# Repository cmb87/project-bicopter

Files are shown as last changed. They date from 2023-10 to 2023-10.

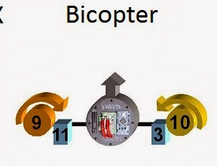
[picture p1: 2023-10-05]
imgs/bicopter.png

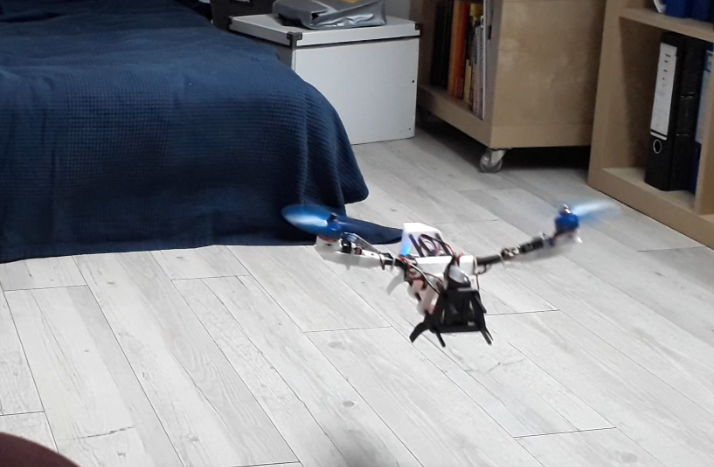
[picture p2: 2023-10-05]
imgs/inflight2.png

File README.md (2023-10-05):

# Bicopter (WIP!)

bicopter with ardiuno, esp, multiwii etc...

# Construction

See https://www.thingiverse.com/thing:6250313

Tilt mechanism is a remix from: https://www.thingiverse.com/thing:1026731

## To buy

    4x 5x5mm carbon rectangular profile
    2x 8x8mm carbon rectangular profile
    2x Emax rs2205
    2x 30A ESC OPTO
    2x MicroServo
    1x Arduino Nano
    1x Battery 75C 11.1V 850mAh
    1x Matek

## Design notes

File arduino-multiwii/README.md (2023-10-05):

# Generic Arduino Based Flightcontroller

## Code
There are two versions:

## MultiWii based FC code
(see https://github.com/multiwii/multiwii-firmware.git for more details). 

### Compass module
Some modifications of the original code were necessary for the compass module (QMC5883L) and are described here:
https://forum.arduino.cc/index.php?topic=556590.0

0.) Navigate to config.h add the line somewhere behind /* I2C magnetometer */:

        #define QMC5883
        
1.) Navigate to sensors.cpp add following somewhere behind the last #endif statement at the magnetometer section:

        // ************************************************************************************************************
        // I2C Compass QMC5883L
        // ************************************************************************************************************
        // I2C adress: 0x0D (7bit)
        // ************************************************************************************************************
        #if defined(QMC5883)

        #define MAG_ADDRESS 0x0D
        #define MAG_DATA_REGISTER 0x00

        //REG CONTROL

        #define MAG_CTRL_REG1 0x09
        #define QMC_MODE 0xC1 // 11 00 00 01OSR=64(11); Range=2G(00); ODR=10Hz(00); MODE=Cont(01)
        #define MAG_CTRL_REG2 0x0A

        void Mag_init() {
          i2c_writeReg(MAG_ADDRESS,0x0B,0x01);
          i2c_writeReg(MAG_ADDRESS,MAG_CTRL_REG1,QMC_MODE);
        }

        static void getADC() {
          i2c_getSixRawADC(MAG_ADDRESS,MAG_DATA_REGISTER);
          MAG_ORIENTATION( ((rawADC[1]<<8) | rawADC[0]) ,
                           ((rawADC[3]<<8) | rawADC[2]) ,
                           ((rawADC[5]<<8) | rawADC[4]) );
        }

        #if !defined(MPU6050_I2C_AUX_MASTER)
        static void Device_Mag_getADC() {
          getADC();
        }
        #endif
        #endif

Now we need to add the QMC to the MPU6050 I2C Master & Slave functionality:

Search for this comment in sensors.cpp:

        //The MAG acquisition function must be replaced because we now talk to the MPU device

Add following lines inside static void Device_Mag_getADC(){} after i2c_getSixRawADC(MPU6050_ADDRESS, 0x49);:

        #if defined(QMC5883)
                MAG_ORIENTATION( ((rawADC[1]<<8) | rawADC[0]) ,
                                 ((rawADC[3]<<8) | rawADC[2]) ,
                                 ((rawADC[5]<<8) | rawADC[4]) );
              #endif
              
Navigate to def.h search for the MAG 1 definition "#if" clause - add "|| defined(QMC5883)" - like this:

        #if defined(HMC5883) || defined(HMC5843) || defined(AK8975) || defined(MAG3110) || defined(QMC5883)
          #define MAG 1
        #else
          #define MAG 0
        #endif
              
The original HMC5883 Code has lots of more lines because of some ominous bias and gain settings - the QMC5883 lacks those registers - Unfortunately I don't have any knowledge about this and its benefits and no time to get into it. The data provided by the sensor seems to be reliable.

### Setup
Due to the construction of the flight controller the following settings were necessary:
            
          MINTHROTTLE = 1150
          # ==============================================
          # MPU Setup 
          # ==============================================
          # Roll and Yaw inverted
          #define ACC_ORIENTATION(X, Y, Z) {imu.accADC[ROLL] =  -X; imu.accADC[PITCH] =  -Y; imu.accADC[YAW] = Z;}
          #define GYRO_ORIENTATION(X, Y, Z) {imu.gyroADC[ROLL] = -X; imu.gyroADC[PITCH] = -Y; imu.gyroADC[YAW] = Z;}
          
          # ==============================================
          # Inverted Pitch ... let's see ===> Not a good idea ... Create oscillations!
          #define ACC_ORIENTATION(X, Y, Z) {imu.accADC[ROLL] =  X; imu.accADC[PITCH] =  Y; imu.accADC[YAW] = -Z;}
          #define GYRO_ORIENTATION(X, Y, Z) {imu.gyroADC[ROLL] = -X; imu.gyroADC[PITCH] = Y; imu.gyroADC[YAW] = -Z;}

          # ==============================================
          WORKING!!!!
          # Roll and Yaw inverted ==> Stabilize around roll axis! Roll appears inverted in MultiwiiConf!!!
          #define ACC_ORIENTATION(X, Y, Z) {imu.accADC[ROLL] =  X; imu.accADC[PITCH] =  -Y; imu.accADC[YAW] = -Z;}
          #define GYRO_ORIENTATION(X, Y, Z) {imu.gyroADC[ROLL] = -X; imu.gyroADC[PITCH] = -Y; imu.gyroADC[YAW] = -Z;}
          # PID Coeff; Roll; 4.1, 0.004,9 Pitch:1.6, 0.003,4 Yaw: 1.6, 0.003, 2
          
          # ==============================================
          # MPU + Compass
          # ==============================================
          WORKING!!!! Works perfectly with 
          #define YAW_DIRECTION -1
          #define ACC_ORIENTATION(X, Y, Z) {imu.accADC[ROLL] =  X; imu.accADC[PITCH] =  -Y; imu.accADC[YAW] = -Z;}
          #define GYRO_ORIENTATION(X, Y, Z) {imu.gyroADC[ROLL] = -X; imu.gyroADC[PITCH] = -Y; imu.gyroADC[YAW] = -Z;}
          #define FORCE_MAG_ORIENTATION(X, Y, Z)  {imu.magADC[ROLL]  =   -X; imu.magADC[PITCH]  =  -Y; imu.magADC[YAW]  = -Z;}

### ESC Calibration
Dont forget the ESC calibration in config.h!

### Custom Arduino based FC code
Inspired by http://www.electronoobs.com

## PCB
Created with Fritzing and Flatcam.

# Issues
Some issues encountered during the construction phase.

## Vibrations
Has a very intensive impact on PID controller resulting in twitches and an in general "nervous" behaviour of the quad. In order to mitigate there are three ways:

    1.) Reduce vibrations by accurately balancing propellers
    2.) Increase damping of the flight controller module
    3.) In MultiWii: Reduce low pass filter to e.g. 42hz for gyro and activate moving average filter (with default settings). Search for LPF in config.h

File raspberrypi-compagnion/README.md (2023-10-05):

# Robotic SocketIO Control Stack
Computer Vision enhanced custom analytics

# Setup

## WiP

    scp -rv * pi@raspberrypi:/home/pi/projects/06_servoTest/.

## Start pigpio on start up

    sudo systemctl enable pigpiod

will enable it to auto-start on boot.

will start it immediately (just a posh way of doing

    sudo pigpiod

:)

If you change your mind,

    sudo systemctl disable pigpiod

will undo the start-up behaviour. Similarly,

    sudo systemctl stop pigpiod

will have an immediate effect.

## PWM Connection PiZero <-> FC

    Throttle D2 - GPIO 5
    Roll     D4 - GPIO 6
    Pitch    D5 - GPIO 13
    Yaw      D6 - GPIO 19
    Aux1     D7 - GPIO 26
    Aux1     D7 - GPIO 16
    Aux1     D7 - GPIO 20
    Aux1     D7 - GPIO 21
    G        GND
    
## Run Python script on every startup
Head over to /etc/profile, add command to start the Python script

    ...
    python3 /home/pi/..../app.py

## Issues

### RPI Slow Wifi network connection

Source (https://raspberrypi.stackexchange.com/questions/52066/pi3-wifi-extremely-slow)
Make sure power management is off on Pi.

    iwconfig

You should see something like this

    Power Management:off

If not, you can switch it to off by using

    sudo iwconfig wlan0 power off

If you want to make this permanent you should add the following line to /etc/rc.local (explanation here):

    iwconfig wlan0 power off

## Based on WiiProxy

https://github.com/engineer-99b/WiiProxy

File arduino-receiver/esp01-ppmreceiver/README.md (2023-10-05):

# Websocket based drone system

## Demo with FD411 Flightcontroller and ESP8266

## SocketIO Versions

	Python:
		Flask==1.1.2
		Flask-Cors==3.0.9
		gevent==20.6.2
		gevent-websocket==0.10.1
		python-engineio==3.13.2
		python-socketio==4.6.1
		Flask-SocketIO==4.3.1
    
	Arduino:
		SocketIOClient==0.3.0 (Vincent Wyszynski)
		WebSockets==2.3.1 (Markus Sattler)

	Angular:
		npm i --save socket.io-client@2.3.1
	Node:
		socket.io": {"version": "2.3.0"}
		engine.io  "version": "3.4.2",
		engine.io-client  3.4.4

## Connection Flightcontroller - Receiver

### PPM FD411 Flightcontroller Betaflight
		FD411s => ESP01
		3.3V => Pin 8 
		GND => Pin1
		RX2 => Pin2 (GPIO1)

## Connections for SBUS
https://github.com/bolderflight/SBUS

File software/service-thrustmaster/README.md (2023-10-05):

# Joystick

Microservice which reads the input of a connected Thrustmaster.
Commands are transferred via socketIO to a MultiWii or Betaflight compatible Device.

### Add Thrustmaster USB Joystick
Device wasnt showed as /dev/ttyUSB0. According to website (https://www.linuxquestions.org/questions/linux-server-73/ttyusb0-not-showing-up-in-dev-827416/):

        mknod /dev/ttyUSB0 c 188 0

# Docker

        docker build -t cmb87/skylink-thrustmaster:latest -f docker/Dockerfile .
        docker run --privileged -v /dev:/dev -e ENV_SOCKETIOSERVER="192.168.2.138"  joystick:latest
        docker push  cmb87/skylink-thrustmaster:latest

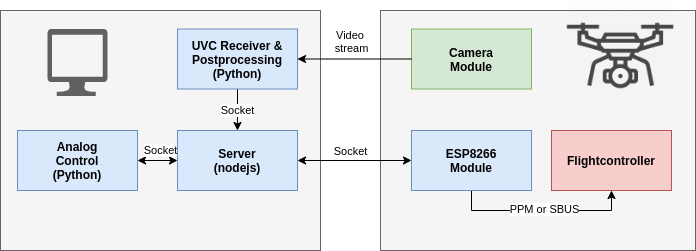
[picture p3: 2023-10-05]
imgs/architecture.png

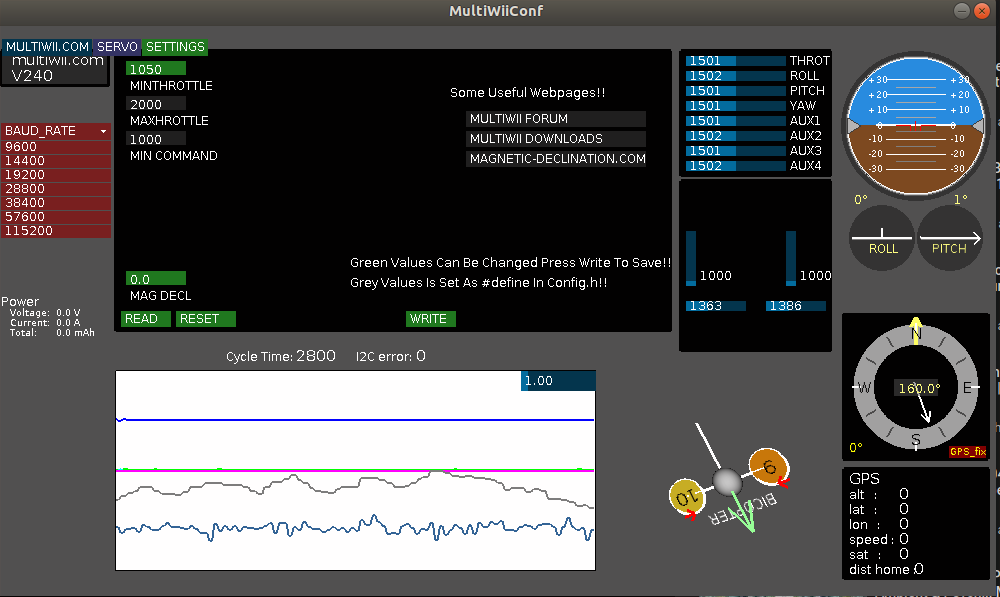
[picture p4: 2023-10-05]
imgs/mw3.png

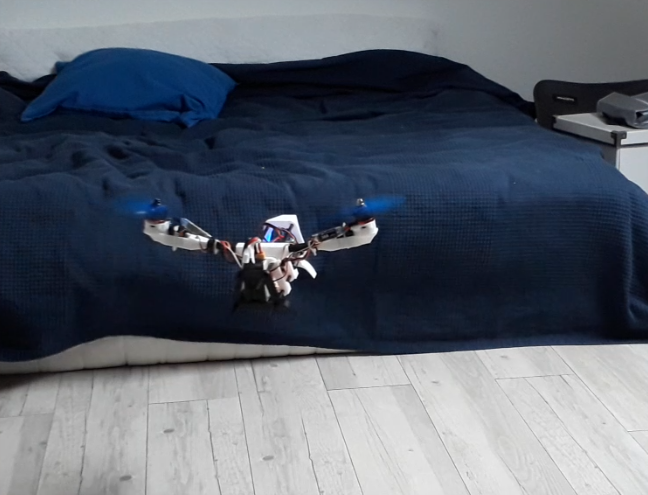
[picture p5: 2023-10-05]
imgs/inflight3.png

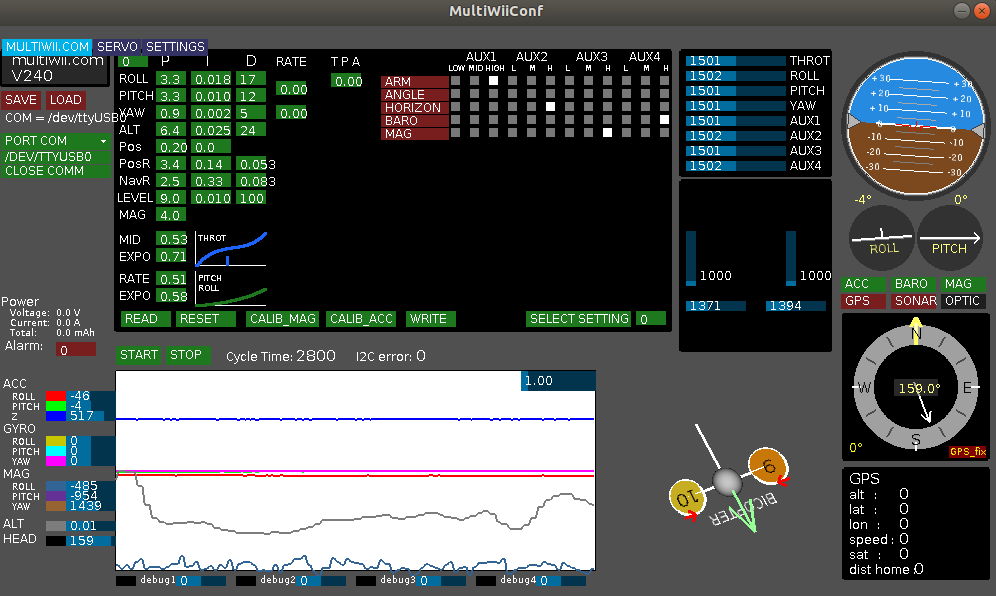
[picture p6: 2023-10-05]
imgs/mw1.png

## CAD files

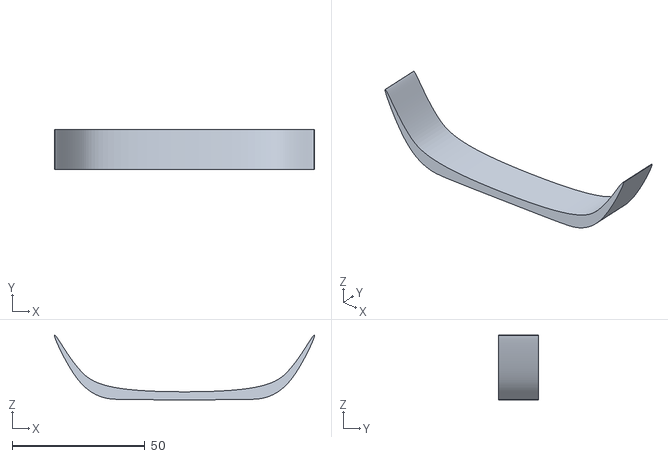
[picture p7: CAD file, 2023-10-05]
construction/3dprinted/landingGearRaw.stl
97.8 x 15.0 x 24.3

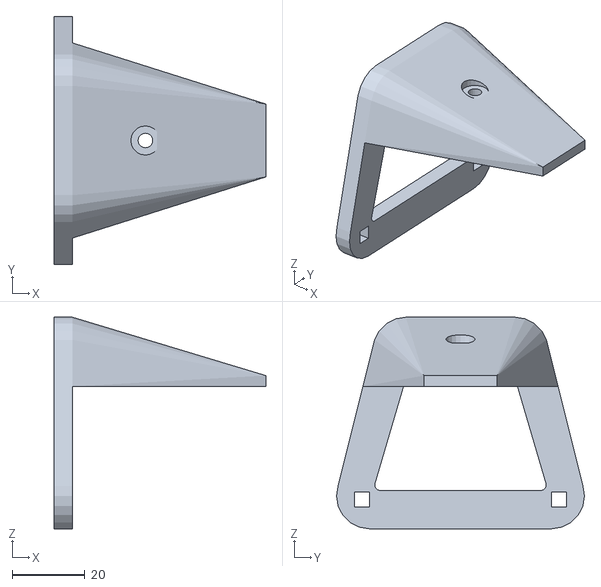
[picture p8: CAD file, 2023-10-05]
construction/3dprinted/nose.stl
58.0 x 68.0 x 58.0

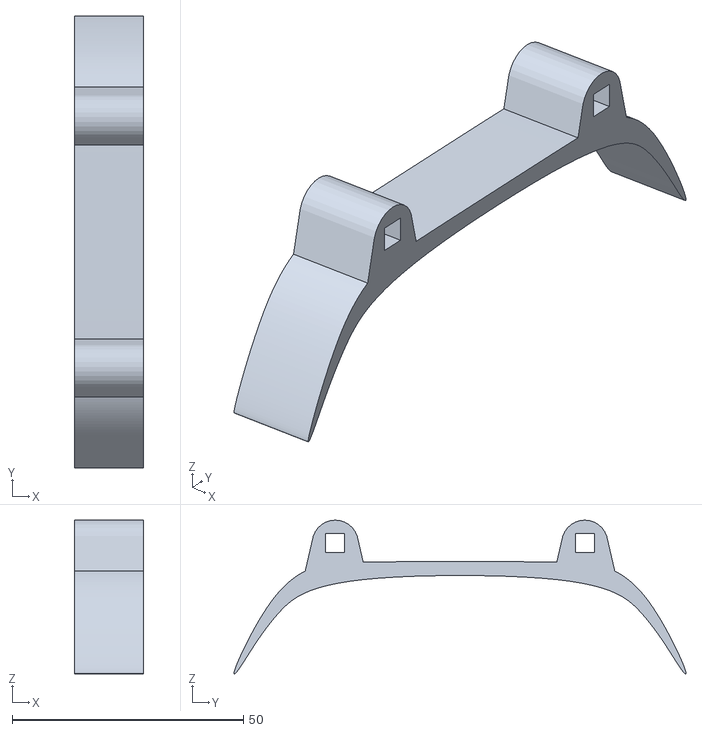
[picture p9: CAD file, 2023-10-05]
construction/3dprinted/landinggearWithoutHolders.stl
15.0 x 97.8 x 33.3

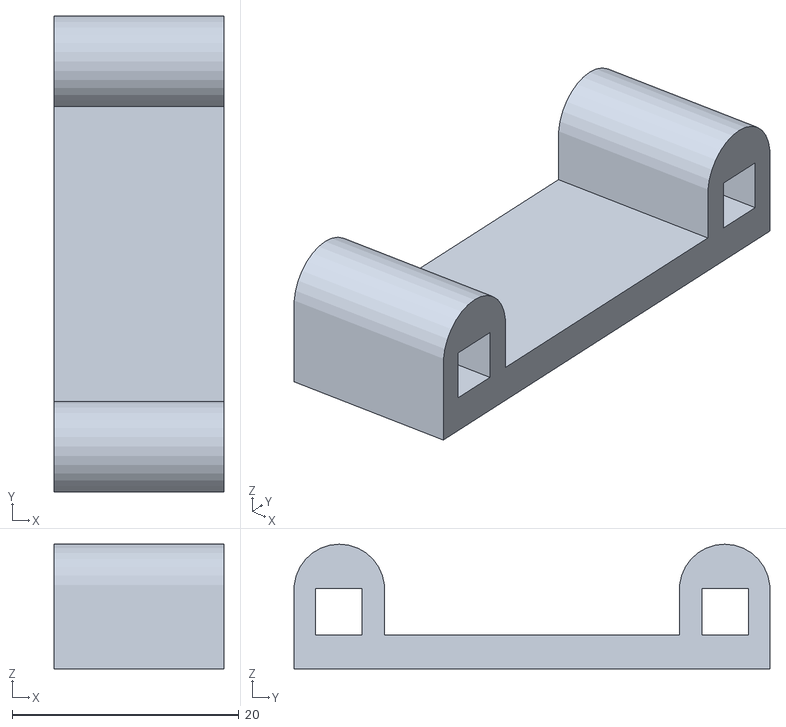
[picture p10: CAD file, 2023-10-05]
construction/3dprinted/gpsholder.stl
15.0 x 42.0 x 11.0

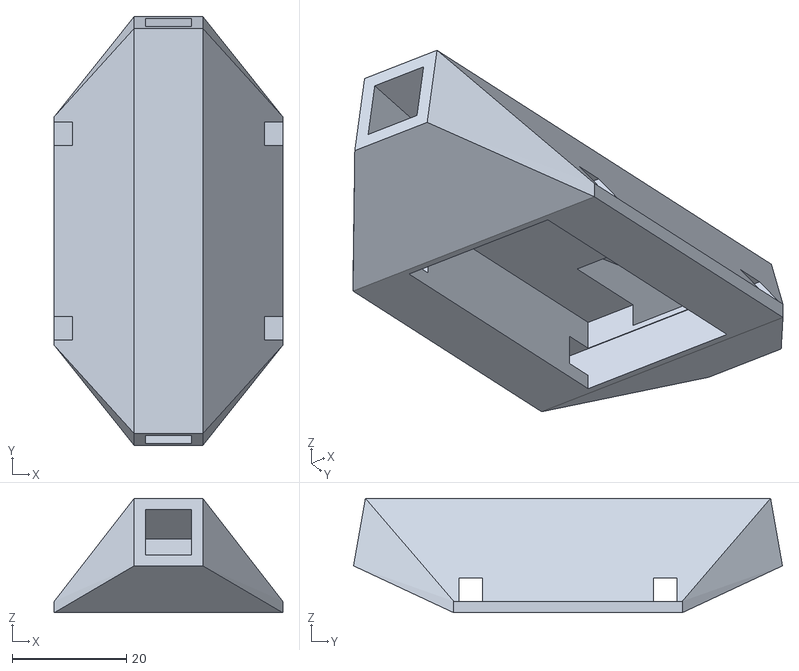
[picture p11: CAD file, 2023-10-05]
construction/3dprinted/frame.stl
40.0 x 75.1 x 20.0

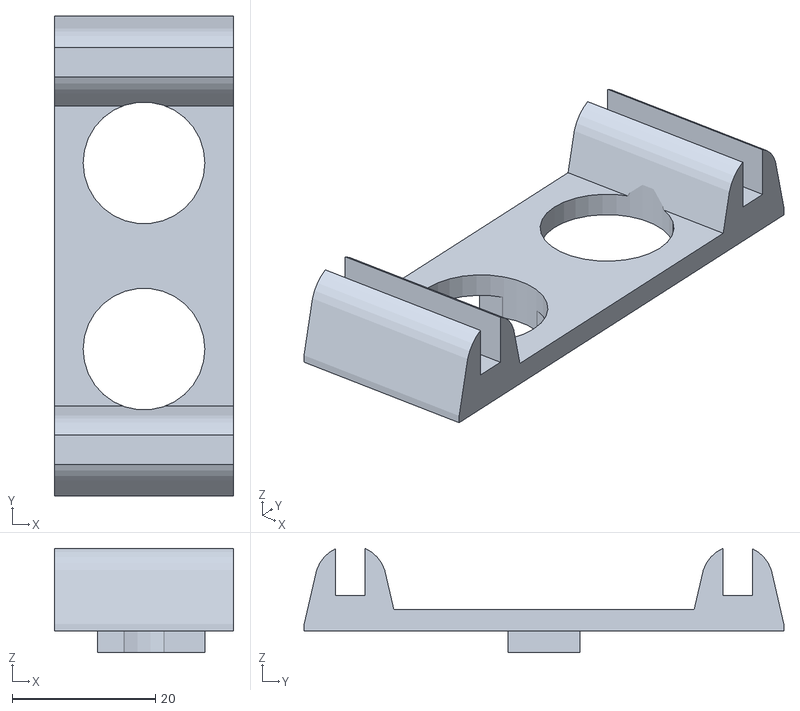
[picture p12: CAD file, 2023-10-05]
construction/3dprinted/sonarholder.stl
25.0 x 67.0 x 14.6

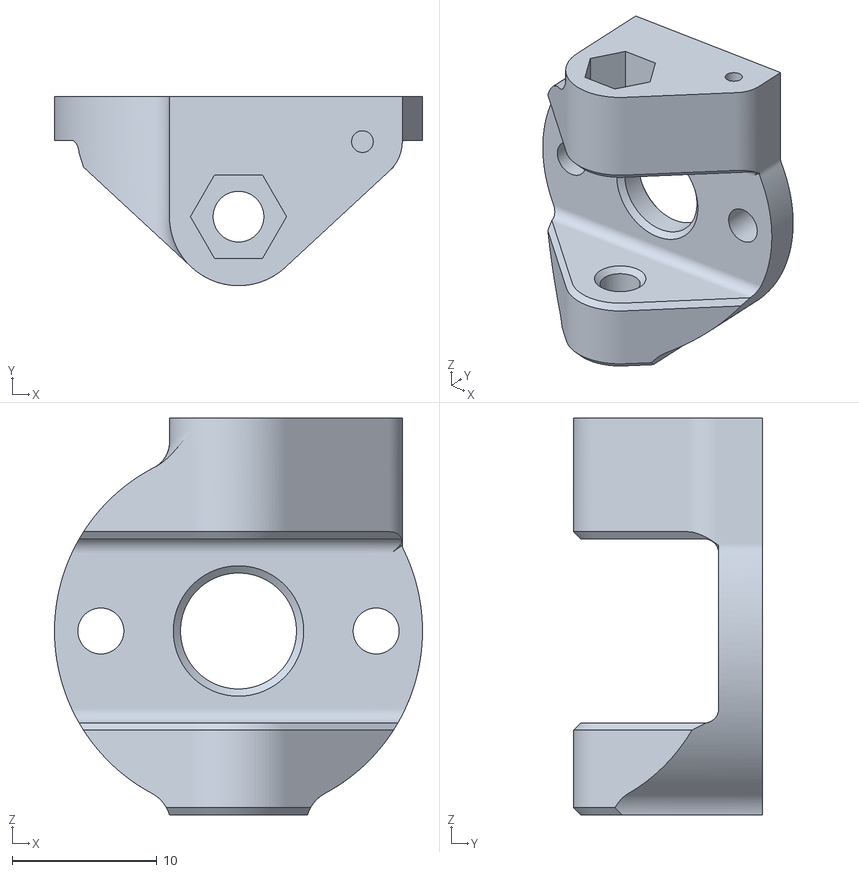
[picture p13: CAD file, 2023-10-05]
construction/3dprinted/TAIL_TILT_V2.stl
25.4 x 13.1 x 27.4

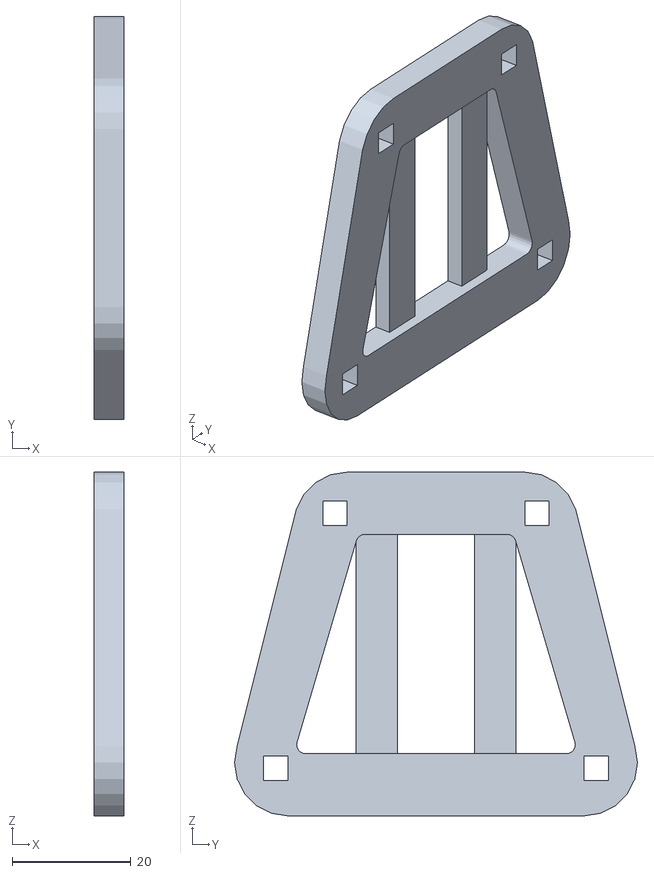
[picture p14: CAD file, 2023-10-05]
construction/3dprinted/batteryBody.stl
5.00 x 68.0 x 58.0

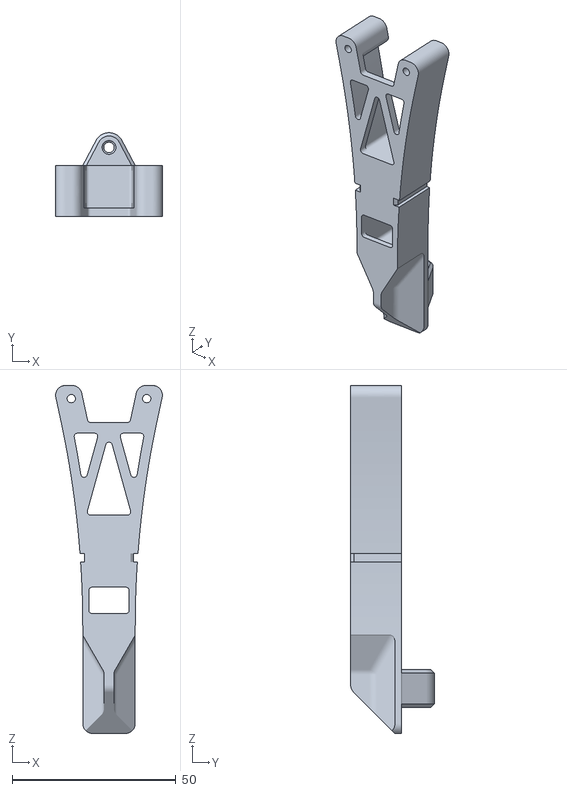
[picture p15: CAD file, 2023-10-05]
construction/3dprinted/TRI_TAIL_V3.stl
32.6 x 25.5 x 106.1

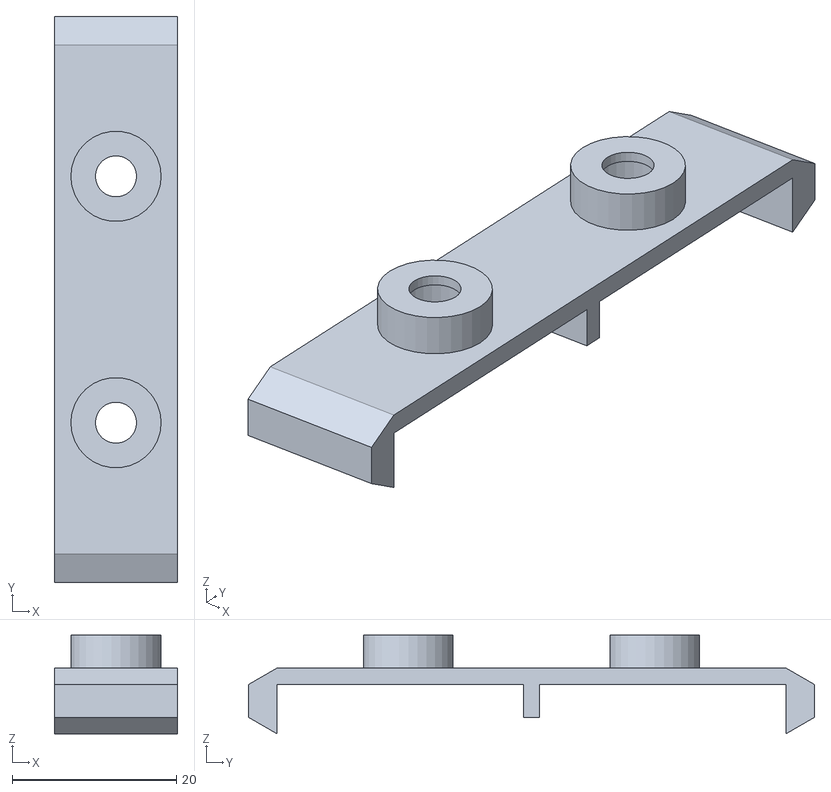
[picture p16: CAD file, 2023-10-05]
construction/3dprinted/hardwareplatform.stl
15.0 x 68.9 x 12.0

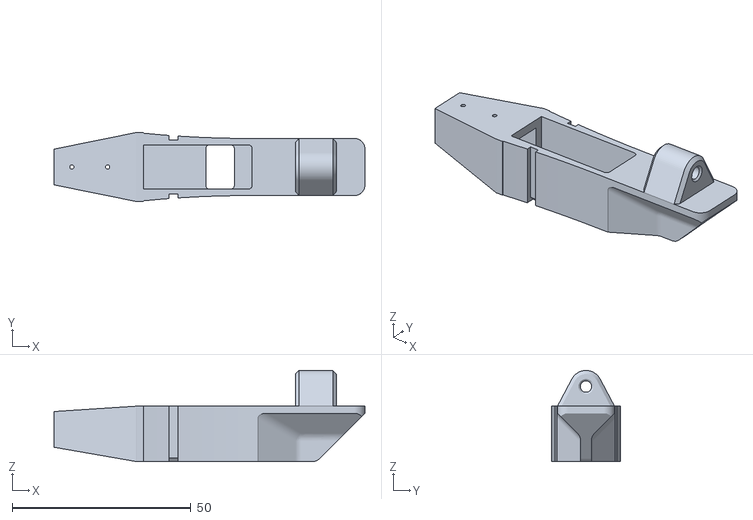
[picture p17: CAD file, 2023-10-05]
construction/3dprinted/arms.stl
87.1 x 19.4 x 25.5

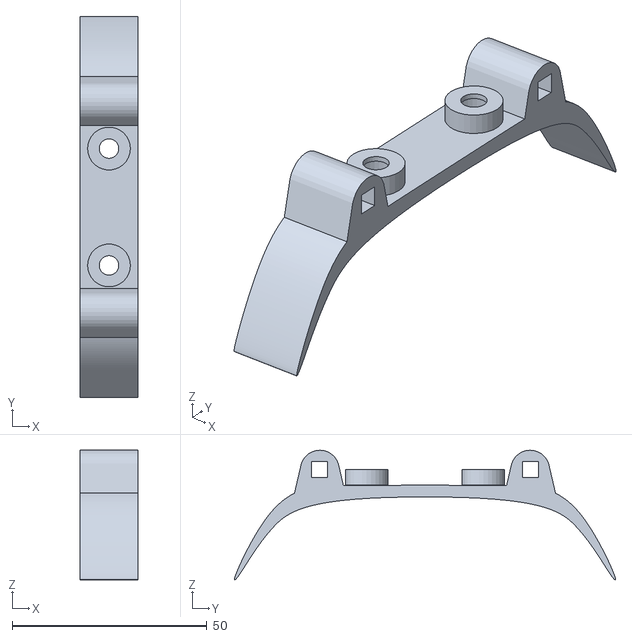
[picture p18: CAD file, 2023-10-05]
construction/3dprinted/landinggear.stl
15.0 x 97.8 x 33.3

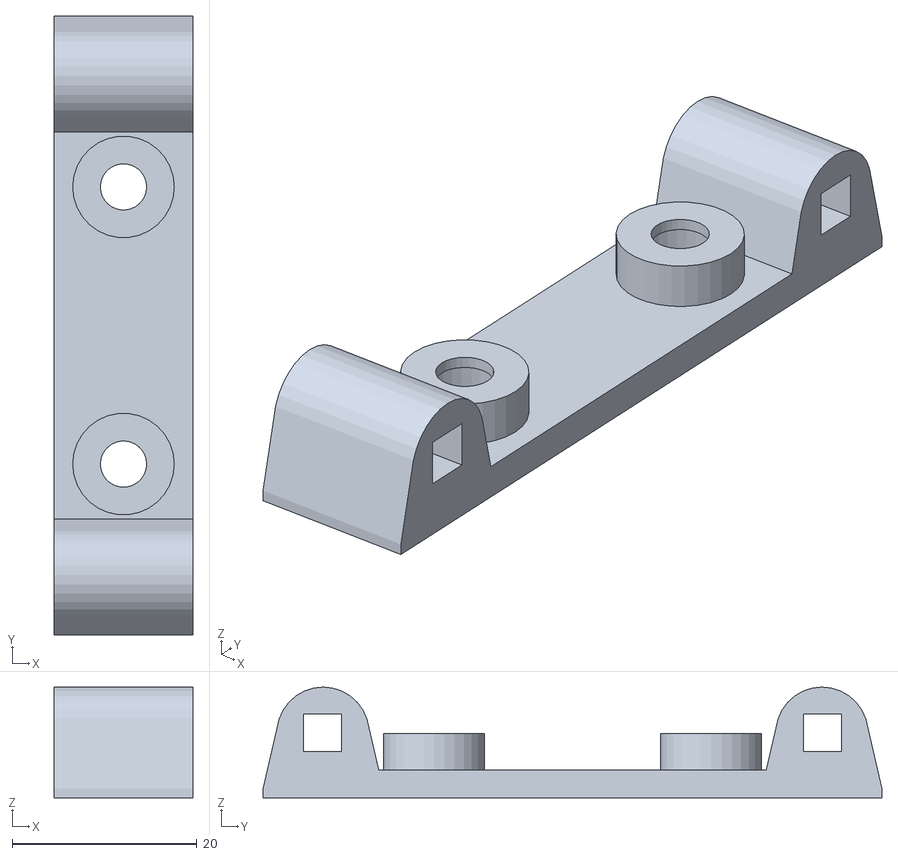
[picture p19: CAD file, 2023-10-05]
construction/3dprinted/hardwareholder.stl
15.0 x 67.0 x 12.0

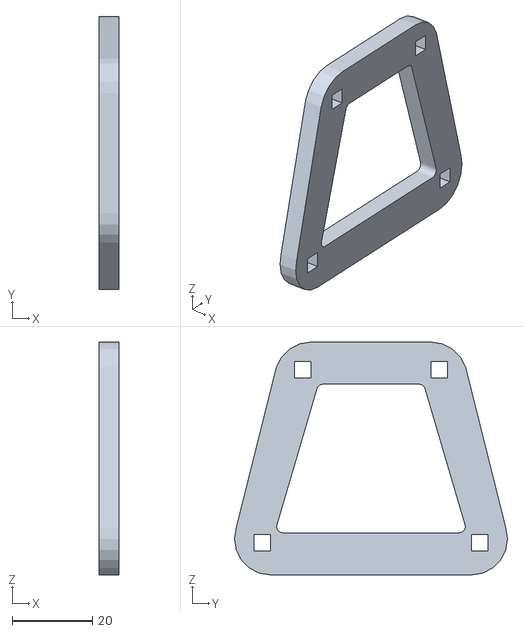
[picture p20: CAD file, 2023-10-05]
construction/3dprinted/body.stl
5.00 x 68.0 x 58.0

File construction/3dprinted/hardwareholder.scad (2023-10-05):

t = 5;

rx = 100;
rdy = 4.1;
roy = 30;
royl = 50;





module rails(oz=2) {
    
  translate([-rx/2,roy/2,oz]) cube([rx,rdy,rdy]);
  mirror([0,1,0]){
    translate([-rx/2,roy/2,oz]) cube([rx,rdy,rdy]);
  }
    
}

module railsLow(oz=2) {
    
  translate([-rx/2,royl/2,oz]) cube([rx,rdy,rdy]);
  mirror([0,1,0]){
    translate([-rx/2,royl/2,oz]) cube([rx,rdy,rdy]);
  }
    
}


difference(){
union(){
  translate([-15/2,-60/2,-3])cube([15,60,3]);
    
  hull(){
    translate([-15/2,27,4])rotate([0,90,0])cylinder(r=5,h=15,$fn=30);
    translate([-15/2,27-13/2,-3])cube([15,13,1]);
  }
  hull(){
    translate([-15/2,-27,4])rotate([0,90,0])cylinder(r=5,h=15,$fn=30);
    translate([-15/2,-27-13/2,-3])cube([15,13,1]);
  }
  
  translate([0,+15,0])cylinder(r=5.5,h=4,$fn=30);
  translate([0,-15,0])cylinder(r=5.5,h=4,$fn=30);
}

  translate([0,15,-5])cylinder(r=2.5,h=15,$fn=30);
  translate([0,15,-7])cylinder(r=4,h=10,$fn=30);

  translate([0,-15,-5])cylinder(r=2.5,h=15,$fn=30);
  translate([0,-15,-7])cylinder(r=4,h=10,$fn=30);
railsLow(oz=2);

}

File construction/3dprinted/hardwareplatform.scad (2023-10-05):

t = 5;

rx = 100;
rdy = 4.1;
roy = 30;
royl = 50;





difference(){
union(){
  translate([-15/2,-62/2,-2])cube([15,62,2]);
    


  translate([0,+15,0])cylinder(r=5.5,h=4,$fn=30);
  translate([0,-15,0])cylinder(r=5.5,h=4,$fn=30);
    
  translate([-15/2,-1,-6])cube([15,2,6]);
  translate([0,31,-4])bracket();
  translate([0,-31,-4])mirror([0,1,0])bracket();
}

  translate([0,15,-5])cylinder(r=2.5,h=15,$fn=30);
  translate([0,15,-7])cylinder(r=4,h=10,$fn=30);
  translate([0,-15,-5])cylinder(r=2.5,h=15,$fn=30);
  translate([0,-15,-7])cylinder(r=4,h=10,$fn=30);



}

module bracket(){
  difference(){
    translate([-7.5,0,0])rotate([0,90,0])cylinder(r=4,h=15,$fn=6);
    translate([-15,-20,-10])cube([30,20,20]);
  }
}

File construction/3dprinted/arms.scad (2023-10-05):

difference(){

union(){
  difference(){
    rotate([90,0,0])rotate([0,-90,0])import("TRI_TAIL_V3.stl");
    translate([-5,-40/2,-1])cube([43,40,20]);
  }
  hull(){
    translate([15,-10/2,4])cube([2,10,10]);
    translate([38,-19.3/2,0])cube([2,19.3,15.5]);
  }


}

translate([20,0,-5])cylinder(r=0.6,h=40, $fn=20);
translate([30,0,-5])cylinder(r=0.6,h=40, $fn=20);
translate([10,-8.1/2,5])cube([32,8.1,8.2]);

}

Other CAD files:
construction/3dprinted/TRI_TAIL_V2.stl
construction/3dprinted/batteryBody.scad
construction/3dprinted/body.scad
construction/3dprinted/frame.scad
construction/3dprinted/gpsholder.scad
construction/3dprinted/landinggear.scad
construction/3dprinted/landinggearWithoutHolders.scad
construction/3dprinted/nose.scad
construction/3dprinted/sonarholder.scad

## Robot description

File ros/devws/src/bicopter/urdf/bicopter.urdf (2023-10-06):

<?xml version="1.0" ?>
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
<robot name="bicopter" xmlns:xacro="http://www.ros.org/wiki/xacro">
  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
  <link name="base_link">
    <inertial>
      <mass value="0.5"/>
      <origin rpy="0 0 0" xyz="0 0 0.05"/>
      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
    </inertial>
    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
  </link>
  <link name="tail">
    <inertial>
      <mass value="0.02085"/>
      <origin rpy="0 1.5708 0" xyz="0 0 0.0"/>
      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
    </inertial>
    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
  </link>
  <link name="prop_right">
    <inertial>
      <mass value="0.01"/>
      <origin rpy="0 0 0" xyz="0 0 0.0"/>
      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
    </inertial>
    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
  </link>
  <link name="prop_left">
    <inertial>
      <mass value="0.01"/>
      <origin rpy="0 0 0" xyz="0 0 0.0"/>
      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
    </inertial>
    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
  </link>
  <link name="arm_left">
    <inertial>
      <mass value="0.05"/>
      <origin rpy="0 -0.1 -1.5707" xyz="-0.010 -0.1 0.02"/>
      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
    </inertial>
    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
  </link>
  <link name="arm_right">
    <inertial>
      <mass value="0.05"/>
      <origin rpy="0 -0.1 1.5707" xyz="-0.010 0.1 0.02"/>
      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
    </inertial>
    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
  </link>
  <link name="motor_right">
    <inertial>
      <mass value="0.035"/>
      <origin rpy="0 0 0" xyz="0 0 0.0"/>
      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
    </inertial>
    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
  </link>
  <link name="motor_left">
    <inertial>
      <mass value="0.035"/>
      <origin rpy="0 0 0" xyz="0 0 0.0"/>
      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
    </inertial>
    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
  </link>
  <joint name="link_base_link_tail" type="fixed">
    <parent link="base_link"/>
    <child link="tail"/>
    <origin xyz="-0.25 0.0 0.05"/>
  </joint>
  <joint name="link_base_link_arm_right" type="fixed">
    <parent link="base_link"/>
    <child link="arm_right"/>
    <origin xyz="0 0.0 0.05"/>
  </joint>
  <joint name="link_base_link_arm_left" type="fixed">
    <parent link="base_link"/>
    <child link="arm_left"/>
    <origin xyz="0 0.0 0.05"/>
  </joint>
  <joint name="arm_right__motor_right" type="revolute">
    <axis xyz="0 1 0"/>
    <limit effort="1000" lower="-0.5" upper="0.5" velocity="0.5"/>
    <origin rpy="0 0 0" xyz="-0.010 0.2 0.04"/>
    <parent link="arm_right"/>
    <child link="motor_right"/>
    <dynamics damping="10.0" friction="10.0"/>
  </joint>
  <joint name="arm_left__motor_left" type="revolute">
    <axis xyz="0 1 0"/>
    <limit effort="1000" lower="-0.5" upper="0.5" velocity="0.5"/>
    <origin rpy="0 0 0" xyz="-0.010 -0.2 0.04"/>
    <parent link="arm_left"/>
    <child link="motor_left"/>
    <dynamics damping="10.0" friction="10.0"/>
  </joint>
  <joint name="motor_left__prop_left" type="continuous">
    <axis xyz="0 0 -1"/>
    <origin rpy="0 0 0" xyz="0.00 -0.0 0.02"/>
    <parent link="motor_left"/>
    <child link="prop_left"/>
  </joint>
  <joint name="motor_right__prop_right" type="continuous">
    <axis xyz="0 0 1"/>
    <origin rpy="0 0 0" xyz="0.00 0.0 0.02"/>
    <parent link="motor_right"/>
    <child link="prop_right"/>
  </joint>
  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
</robot>

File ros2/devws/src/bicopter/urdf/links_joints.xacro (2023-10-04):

<?xml version="1.0" ?>
<robot xmlns:xacro="http://www.ros.org/wiki/xacro">

  <xacro:macro name="m_joint" params="name type axis_xyz origin_rpy origin_xyz parent child limit_e limit_l limit_u limit_v">
    <joint name="${name}" type="${type}">
      <axis xyz="${axis_xyz}" />
      <limit effort="${limit_e}" lower="${limit_l}" upper="${limit_u}" velocity="${limit_v}" />
      <origin rpy="${origin_rpy}" xyz="${origin_xyz}" />
      <parent link="${parent}" />
      <child link="${child}" />
      <dynamics damping="10.0" friction="10.0"/>
    </joint>
  </xacro:macro>

  <xacro:macro name="m_axis" params="name axis_xyz origin_rpy origin_xyz parent child">
    <joint name="${name}" type="continuous">
      <axis xyz="${axis_xyz}" />
      <origin rpy="${origin_rpy}" xyz="${origin_xyz}" />
      <parent link="${parent}" />
      <child link="${child}" />
    </joint>
  </xacro:macro>


  <xacro:macro name="m_link_cylinder" params="name origin_xyz origin_rpy radius length mass ixx ixy ixz iyy iyz izz material">
    <link name="${name}">
      <inertial>
        <mass value="${mass}" />
        <origin rpy="${origin_rpy}" xyz="${origin_xyz}" />
        <inertia ixx="${ixx}" ixy="${ixy}" ixz="${ixz}" iyy="${iyy}" iyz="${iyz}" izz="${izz}" />
      </inertial>
      <collision>
        <origin rpy="${origin_rpy}" xyz="${origin_xyz}" />
        <geometry>
          <cylinder radius="${radius}" length="${length}" />
        </geometry>
      </collision>
      <visual>
        <origin rpy="${origin_rpy}" xyz="${origin_xyz}" />
        <geometry>
          <cylinder radius="${radius}" length="${length}" />
        </geometry>
        <material name="${material}"/>
      </visual>
    </link>
  </xacro:macro>

  <xacro:macro name="m_link_box" params="name origin_xyz origin_rpy size mass ixx ixy ixz iyy iyz izz material">
    <link name="${name}">
      <inertial>
        <mass value="${mass}" />
        <origin rpy="${origin_rpy}" xyz="${origin_xyz}" />
        <inertia ixx="${ixx}" ixy="${ixy}" ixz="${ixz}" iyy="${iyy}" iyz="${iyz}" izz="${izz}" />
      </inertial>
      <collision>
        <origin rpy="${origin_rpy}" xyz="${origin_xyz}" />
        <geometry>
          <box size="${size}" />
        </geometry>
      </collision>
      <visual>
        <origin rpy="${origin_rpy}" xyz="${origin_xyz}" />
        <geometry>
          <box size="${size}" />
        </geometry>
        <material name="${material}"/>
      </visual>
    </link>
  </xacro:macro>

  <xacro:macro name="m_link_mesh" params="name origin_xyz origin_rpy meshfile meshscale mass ixx ixy ixz iyy iyz izz">
    <link name="${name}">
      <inertial>
        <mass value="${mass}" />
        <origin rpy="${origin_rpy}" xyz="${origin_xyz}" />
        <inertia ixx="${ixx}" ixy="${ixy}" ixz="${ixz}" iyy="${iyy}" iyz="${iyz}" izz="${izz}" />
      </inertial>
      <collision>
        <origin rpy="${origin_rpy}" xyz="${origin_xyz}" />
        <geometry>
          <mesh filename="${meshfile}" scale="${meshscale}"/>
        </geometry>
      </collision>
      <visual>
        <origin rpy="${origin_rpy}" xyz="${origin_xyz}" />
        <geometry>
          <mesh filename="${meshfile}" scale="${meshscale}"/>
        </geometry>
        <material name="light_black"/>
      </visual>
    </link>
  </xacro:macro>

</robot>

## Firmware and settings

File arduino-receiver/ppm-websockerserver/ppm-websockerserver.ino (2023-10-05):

// https://github.com/steveio/arduino/blob/master/ESP8266RotaryEncoderServo/ESP8266RotaryEncoderServo.ino


#include <WebSocketsServer.h>
#include <ESP8266WiFi.h>
#include "config.h"

const char* ssid = WIFI_SSID;
const char* password = WIFI_PASSWORD;
const char* ssid2 = WIFI_SSID2;
const char* password2 = WIFI_PASSWORD2;

const char* deviceName = DEVICE_NAME;

WebSocketsServer webSocket = WebSocketsServer(WEBSOCKETPORT);

bool connected = false;
uint8_t cam_num;

// ==============================================
// ==============================================
/////////////////////////////////////
////// PPM //////
///////////////////////////////////
// ESP8266 ESP-01S über CH340G USB-Konverter!
/* Set these to your desired credentials. */

#define CPU_MHZ 80
#define CHANNEL_NUMBER 8  //set the number of chanels
#define CHANNEL_DEFAULT_VALUE 1500  //set the default servo value
#define FRAME_LENGTH 22500  //set the PPM frame length in microseconds (1ms = 1000µs)
#define PULSE_LENGTH 300  //set the pulse length
#define onState 0  //set polarity of the pulses: 1 is positive, 0 is negative
#define sigPin SIGPN //set PPM signal output pin on the arduino

volatile unsigned long next;
unsigned int alivecount = 0;

int ppm[CHANNEL_NUMBER];


/// Pin Settings ///
int LEDPin = 2;
int buttonPin = 0;
bool LEDState = false;
int lastUpdate = 0;
int lastTransmission = 0;
// ==============================================
// Data Package settings

// data message
typedef struct data_t
{
  int pitch;
  int yaw;
  int throttle;
  int roll;
  int aux1;
  int aux2;
  int aux3;
  int aux4;
};

// message packaging / envelope
typedef union packet_t {
  struct data_t data;
  uint8_t packet[sizeof(struct data_t)];
};

#define PACKET_SIZE sizeof(struct data_t)

union packet_t receiveMsg;

// buffer
uint8_t byteArray[PACKET_SIZE];



// ==============================================
void setup_wifi() {

  delay(10);
  // We start by connecting to a WiFi network
  Serial.println();


  // scan....
  int n = WiFi.scanNetworks();
  for (int i = 0; i < n; ++i) {
    if (WiFi.SSID(i)== ssid ) {
      WiFi.mode(WIFI_STA);
      WiFi.begin(ssid,password); //trying to connect the modem
      Serial.print("Connecting to ");
      Serial.println(ssid);
      break;
    }
    if (WiFi.SSID(i)== ssid2) {
      WiFi.mode(WIFI_STA);
      WiFi.begin(ssid2,password2); //trying to connect the modem
      Serial.print("Connecting to ");
      Serial.println(ssid2);
     break;
    }
  }


  while (WiFi.status() != WL_CONNECTED) {
    digitalWrite(LEDPin, LEDState);
    LEDState = !LEDState;
    delay(500);
  }

  randomSeed(micros());

  Serial.println("");
  Serial.println("WiFi connected");
  Serial.println("IP address: ");
  Serial.println(WiFi.localIP());

}
// ==============================================
// https://github.com/Links2004/arduinoWebSockets/issues/192

void webSocketEvent(uint8_t num, WStype_t type, uint8_t * payload, size_t length) {

  switch (type) {
    case WStype_DISCONNECTED:
      Serial.printf("[%u] Disconnected!\n", num);
      break;
    case WStype_CONNECTED:
      Serial.printf("[%u] Client Connected!\n", num);
      cam_num = num;
      connected = true;
      break;
    case WStype_TEXT:
      Serial.printf("[%u] get Text: %s\n", num, payload);
      break;

    case WStype_BIN:
      readByteArray(payload);
//      Serial.print(ppm[0]);
//      Serial.print(" ");
//      Serial.print(ppm[1]);
//      Serial.print(" ");
//      Serial.print(ppm[2]);
//      Serial.print(" ");
//      Serial.print(ppm[3]);
//      Serial.print(" ");
//      Serial.print(ppm[4]);
//      Serial.print(" ");
//      Serial.print(ppm[5]);
//      Serial.print(" ");
//      Serial.print(ppm[6]);
//      Serial.print(" ");
//      Serial.print(ppm[7]);
//      Serial.println();
      break;

      //        case WStype_ERROR:
      //        case WStype_FRAGMENT_TEXT_START:
      //        case WStype_FRAGMENT_BIN_START:
      //        case WStype_FRAGMENT:
      //        case WStype_FRAGMENT_FIN:


  }
}

// ==============================================
// read bytes from buffer
void readByteArray(uint8_t * byteArray)
{
  for (int i = 0; i < PACKET_SIZE; i++)
  {
    receiveMsg.packet[i] = byteArray[i];
  }

  // Update ppm signals
  ppm[0] = receiveMsg.data.pitch;
  ppm[1] = receiveMsg.data.yaw;
  ppm[2] = receiveMsg.data.throttle;
  ppm[3] = receiveMsg.data.roll;
  ppm[4] = receiveMsg.data.aux1;
  ppm[5] = receiveMsg.data.aux2;
  ppm[6] = receiveMsg.data.aux3;
  ppm[7] = receiveMsg.data.aux4;

  if (receiveMsg.data.aux1 > 1500) digitalWrite(LEDPin, true);
  if (receiveMsg.data.aux1 < 1500) digitalWrite(LEDPin, false);

  lastUpdate = millis();

}
// ==============================================

void setup() {

  Serial.begin(115200);

  pinMode(LEDPin, OUTPUT);
  pinMode(buttonPin, INPUT);
  pinMode(sigPin, OUTPUT);

  // Connect to wifi
  setup_wifi();
  setup_PPM();

  // Start Websocket Server
  webSocket.begin();
  webSocket.onEvent(webSocketEvent);
  Serial.println("WebsocketServer Online :)");
}
// ==============================================
void loop() {
  // let the websockets client check for incoming messages
  webSocket.loop();

  // If a too long timeout occurs, reset websocket!
  if ((millis() - lastUpdate) >= 2000 ) {
    //Serial.print("Timeout! Resetting commands");
    lastUpdate = millis();
    default_values();
  }

  // Transmit RSSI
  if(connected == true && (millis() - lastTransmission) >= 2000){
    long rssi = WiFi.RSSI();
    String rssi_str = String(rssi);
    webSocket.broadcastTXT(rssi_str);
  } 
  
}

// ==============================================
// PPM Fun
// ==============================================


// ==============================================
void default_values() {
  // Default values
  ppm[0] = 1500;
  ppm[1] = 1500;
  ppm[2] = 1000;
  ppm[3] = 1500;
  ppm[4] = 1000;
  ppm[5] = 1000;
  ppm[6] = 1000;
  ppm[7] = 1000;
}
// ==============================================
void inline ppmISR(void) {
  static boolean state = true;

  if (state) {  //start pulse
    digitalWrite(sigPin, onState);
    next = next + (PULSE_LENGTH * CPU_MHZ);
    state = false;
    alivecount++;
  }
  else { //end pulse and calculate when to start the next pulse
    static byte cur_chan_numb;
    static unsigned int calc_rest;

    digitalWrite(sigPin, !onState);
    state = true;

    if (cur_chan_numb >= CHANNEL_NUMBER) {
      cur_chan_numb = 0;
      calc_rest = calc_rest + PULSE_LENGTH;//
      next = next + ((FRAME_LENGTH - calc_rest) * CPU_MHZ);
      calc_rest = 0;
      // digitalWrite(DEBUGPIN, !digitalRead(DEBUGPIN));
    }
    else {
      next = next + ((ppm[cur_chan_numb] - PULSE_LENGTH) * CPU_MHZ);
      calc_rest = calc_rest + ppm[cur_chan_numb];
      cur_chan_numb++;
    }
  }
  timer0_write(next);
}
// ==============================================

void setup_PPM() {
  // PPM
  digitalWrite(sigPin, !onState); //set the PPM signal pin to the default state (off)

  noInterrupts();
  timer0_isr_init();
  timer0_attachInterrupt(ppmISR);
  next = ESP.getCycleCount() + 1000;
  timer0_write(next);
  for (int i = 0; i < CHANNEL_NUMBER; i++) {
    ppm[i] = CHANNEL_DEFAULT_VALUE;
  }
  interrupts();

}

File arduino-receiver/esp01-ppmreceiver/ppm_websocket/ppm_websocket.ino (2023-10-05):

#include <Arduino.h>
#include <ESP8266WiFi.h>
#include <WebSocketsClient.h>
#include <SocketIoClient.h>
#include <ArduinoJson.h>
#include <SoftwareSerial.h>
#include <MSP.h>

// =================== CONFIG =================== 
/////////////////////////////////////
////// USER DEFINED VARIABLES //////
///////////////////////////////////
/// WIFI Settings ///
const char* ssid     = "";
const char* password = "";

/// Socket.IO Settings ///
char host[] = ""; // Socket.IO Server Address
int port = 5000; // Socket.IO Port Address

/// Pin Settings ///
int LEDPin = 2;
int buttonPin = 0;
bool LEDState = false;

// ------------------------------------------------
/////////////////////////////////////
////// ESP32 Socket.IO Client //////
///////////////////////////////////

SocketIoClient webSocket;

// Use WiFiClient class to create TCP connections
WiFiClient client;

// ------------------------------------------------
/////////////////////////////////////
////// PPM //////
///////////////////////////////////
// ESP8266 ESP-01S über CH340G USB-Konverter! 
/* Set these to your desired credentials. */

#define CPU_MHZ 80
#define CHANNEL_NUMBER 8  //set the number of chanels
#define CHANNEL_DEFAULT_VALUE 1500  //set the default servo value
#define FRAME_LENGTH 22500  //set the PPM frame length in microseconds (1ms = 1000µs)
#define PULSE_LENGTH 300  //set the pulse length
#define onState 0  //set polarity of the pulses: 1 is positive, 0 is negative
#define sigPin 1 //set PPM signal output pin on the arduino


volatile unsigned long next;
unsigned int alivecount=0;

int ppm[CHANNEL_NUMBER];

// ------------------------------------------------
void inline ppmISR(void){
  static boolean state = true;

  if (state) {  //start pulse
    digitalWrite(sigPin, onState);
    next = next + (PULSE_LENGTH * CPU_MHZ);
    state = false;
    alivecount++;
  } 
  else{  //end pulse and calculate when to start the next pulse
    static byte cur_chan_numb;
    static unsigned int calc_rest;
  
    digitalWrite(sigPin, !onState);
    state = true;

    if(cur_chan_numb >= CHANNEL_NUMBER){
      cur_chan_numb = 0;
      calc_rest = calc_rest + PULSE_LENGTH;// 
      next = next + ((FRAME_LENGTH - calc_rest) * CPU_MHZ);
      calc_rest = 0;
     // digitalWrite(DEBUGPIN, !digitalRead(DEBUGPIN));
    }
    else{
      next = next + ((ppm[cur_chan_numb] - PULSE_LENGTH) * CPU_MHZ);
      calc_rest = calc_rest + ppm[cur_chan_numb];
      cur_chan_numb++;
    }     
  }
  timer0_write(next);
}

// =================== SETUP =================== 
// ------------------------------------------------
void setup() {

  Serial.begin(115200);
  Serial.println("Initializing");
  
  delay(1000);

  pinMode(LEDPin, OUTPUT);
  pinMode(buttonPin, INPUT);

  // Connect to Wifi
  WiFi.mode(WIFI_STA);
  WiFi.begin(ssid, password);

  while (WiFi.status() != WL_CONNECTED) {
    digitalWrite(LEDPin, LEDState);
    LEDState = !LEDState;
    delay(500);
  }
  
  // PPM
  pinMode(sigPin,OUTPUT);
  digitalWrite(sigPin, !onState); //set the PPM signal pin to the default state (off)

  noInterrupts();
  timer0_isr_init();
  timer0_attachInterrupt(ppmISR);
  next=ESP.getCycleCount()+1000;
  timer0_write(next);
  for(int i=0; i<CHANNEL_NUMBER; i++){
    ppm[i]= CHANNEL_DEFAULT_VALUE;
  }
  interrupts();

  // Setup 'on' listen events
  webSocket.begin(host, port);
  
  webSocket.on("connect", socket_connected);
  webSocket.on("control", socket_controlHandler);
  webSocket.on("disconnect", socket_disconnected);
  webSocket.on("toggleled", socket_statechange);

}
// =================== MAIN LOOP =================== 
// ------------------------------------------------
void loop() {
  // put your main code here, to run repeatedly:
  webSocket.loop();
}



// =================== FUNCTIONS =================== 
// ----------------
void socket_statechange(const char * payload, size_t length) {
  digitalWrite(LEDPin, LEDState);
  LEDState = !LEDState;
}

// ----------------
void socket_connected(const char * payload, size_t length) {
}
// ----------------
void socket_disconnected(const char * payload, size_t length) {
}
// ----------------
void socket_controlHandler(const char * payload, size_t length) {

//   Serial.print(payload);
  
// https://arduinojson.org/v6/assistant/

  DynamicJsonDocument doc(128);
  deserializeJson(doc, payload);
  
//  MultiWii
// PITCH,YAW,THROTTLE,ROLL,AUX1,AUX2,AUX3,AUX4,8,9,10,11
  ppm[0] = doc[0]; // 1500
  ppm[1] = doc[1]; // 1500
  ppm[2] = doc[2]; // 1599
  ppm[3] = doc[3]; // 1414
  ppm[4] = doc[4]; // 1500
  ppm[5] = doc[5]; // 1400
  ppm[6] = doc[6]; // 1500
  ppm[7] = doc[7]; // 1400

}

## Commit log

2023-10-05 added fc
    [bicopter.xacro, controller.fzz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]
2023-10-05 added ros noetic support
    [bicopter.urdf, bicopter.xacro, links_joints.xacro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]
2023-10-09 fixed ros2
    [bicopter.xacro, links_joints.xacro, robot_parameters.xacro]
